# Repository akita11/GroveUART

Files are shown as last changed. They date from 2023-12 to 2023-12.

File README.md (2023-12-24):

# GroveUART

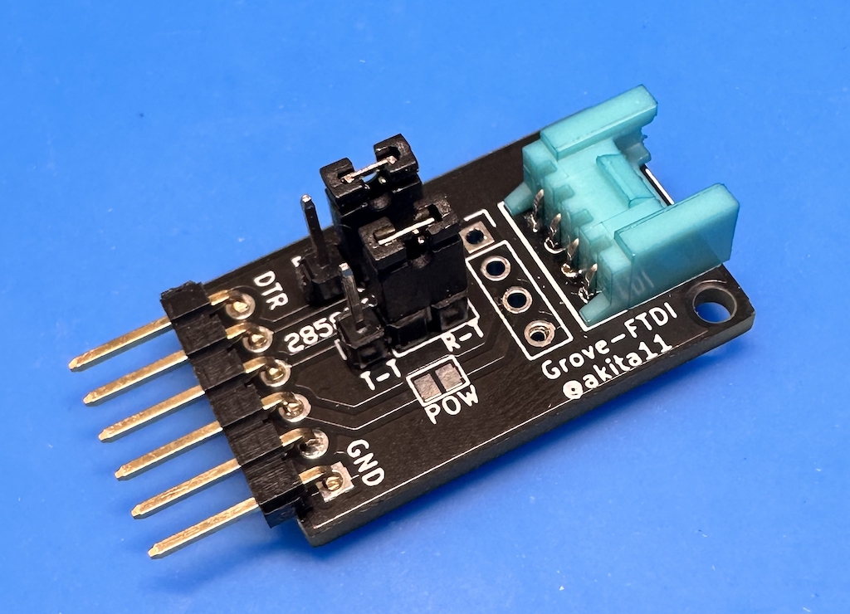
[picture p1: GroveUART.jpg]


GroveケーブルのUART信号を、FTDI-Basic等のUSBシリアル変換器の標準的な6ピンコネクタに接続します。両者の送信(TX)と受信(RX)の接続を切り替えらるので、ストレート結線・リバース結線の両者の使い方ができます。またソルダージャンパをショートすることでFTDI-Basic側の電源をGroveコネクタ側に供給することができます。

## 使い方

M5Stack等からのUART信号の出ているGroveケーブルをGroveコネクタ側に接続し、6ピンコネクタ側には[FTDI-Basic等のUSB-シリアル変換器](https://www.switch-science.com/products/2782)を接続します。Groveケーブル側のUART信号にあわせて、以下のように2箇所のショートピンを設定します。

また裏面のJP1をハンダでショートすることで、FTDI-Basicからの電源をGroveコネクタ側に供給することができます。

### Grove側がUART親機側(M5Stack等)の場合

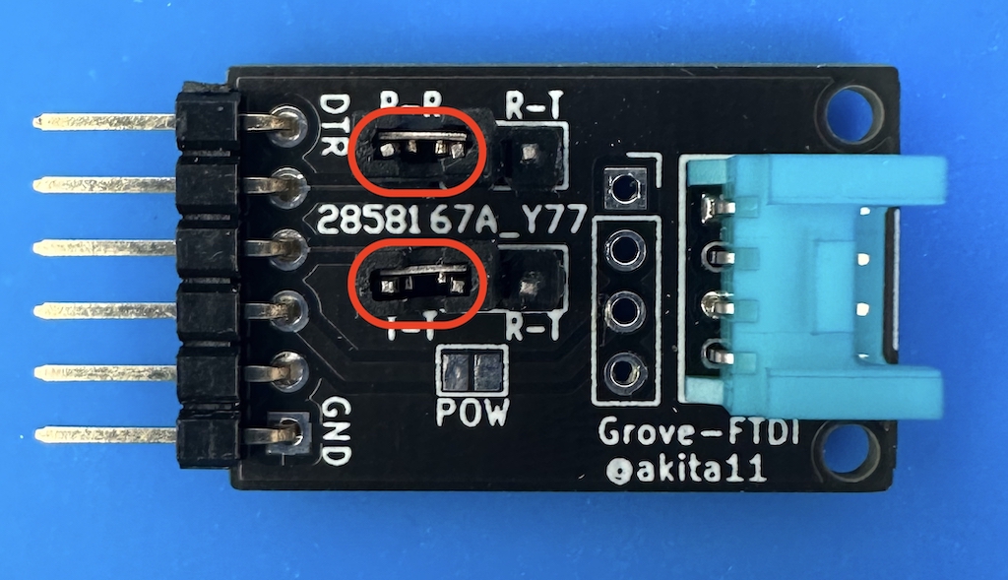
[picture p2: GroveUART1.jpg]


このようにR-R側、T-T側にショートピンを接続します。これにより、以下のように接続されます。

- Groveの1番ピン（端）: FTDI-BasicのTXD(TXo)側
- Groveの2番ピン（その横）: FTDI-basicのRXD(RXi)側

※Groveの1番／2番ピンは、M5StackのPortCのGPIO16(RXD2)/17(TXD2)(Basicの場合)や、GPIO13(RXD2)/14(TXD2)(Core2)です。

### Grove側がUART子機側(Groveセンサ等等)の場合

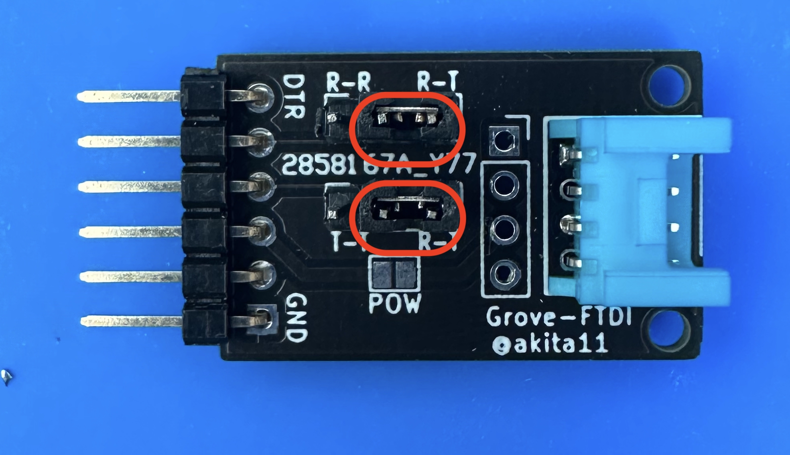
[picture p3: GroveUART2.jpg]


このようにR-T側、R-T側にショートピンを接続します。これにより、以下のように接続されます。

- Groveの1番ピン（端）: FTDI-basicのRXD(RXi)側
- Groveの2番ピン（その横）: FTDI-BasicのTXD(TXo)側

※例えばM5Stack UnitV2では、Groveの1番ピンは"Rx”と表記されていますが、これは「接続先(M5StackBasic等)がRx」という意味ですので、UnitV2にとっては出力(TX)です。

## Author

Junichi Akita (akita@ifdl.jp, @akita11)

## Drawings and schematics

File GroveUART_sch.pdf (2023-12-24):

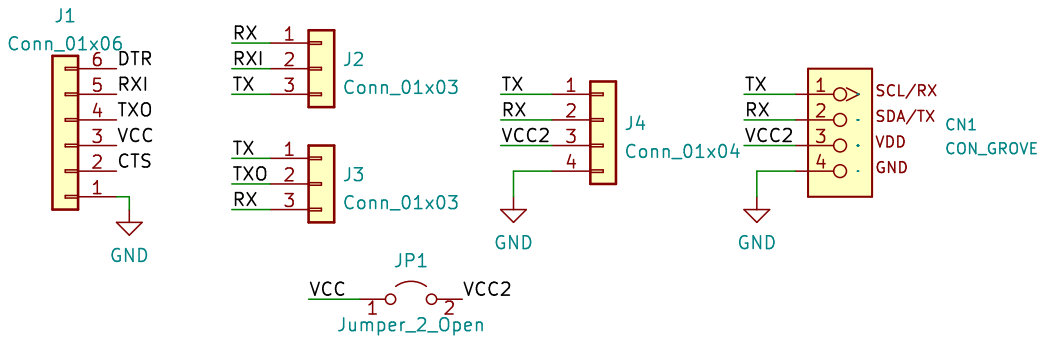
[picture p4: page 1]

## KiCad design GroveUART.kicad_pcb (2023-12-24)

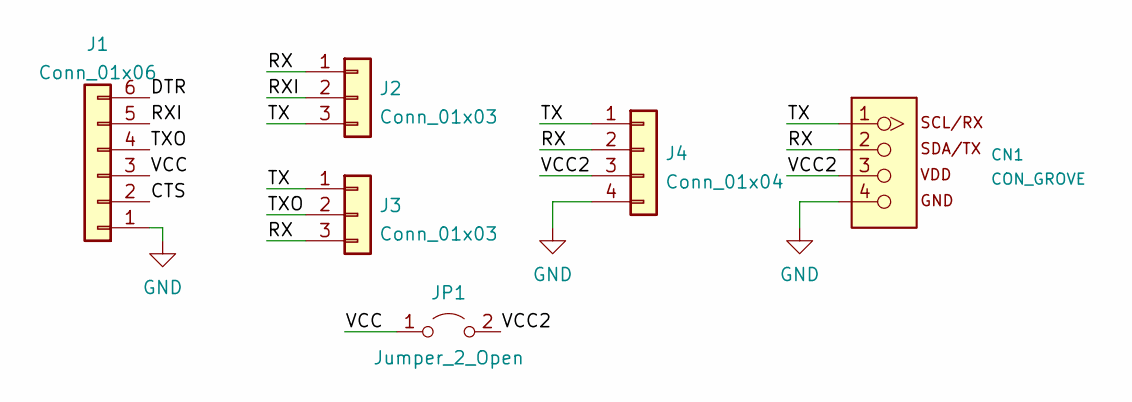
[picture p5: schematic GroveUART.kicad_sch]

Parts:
CN1: CON_GROVE; CON_GROVE_H
J1: Conn_01x06; PinHeader_1x06_P2.54mm_Horizontal
J2, J3: Conn_01x03; PinSocket_1x03_P2.54mm_Vertical
J4: Conn_01x04; PinSocket_1x04_P2.54mm_Vertical
JP1: Jumper_2_Open; SolderJumper-2_P1.3mm_Open_Pad1.0x1.5mm

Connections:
/CTS: J1.2
/DTR: J1.6
/RX: CN1.2, J2.1, J3.3, J4.2
/RXI: J1.5, J2.2
/TX: CN1.1, J2.3, J3.1, J4.1
/TXO: J1.4, J3.2
/VCC: J1.3, JP1.1 (A)
/VCC2: CN1.3, J4.3, JP1.2 (B)
GND: CN1.4, J1.1, J4.4

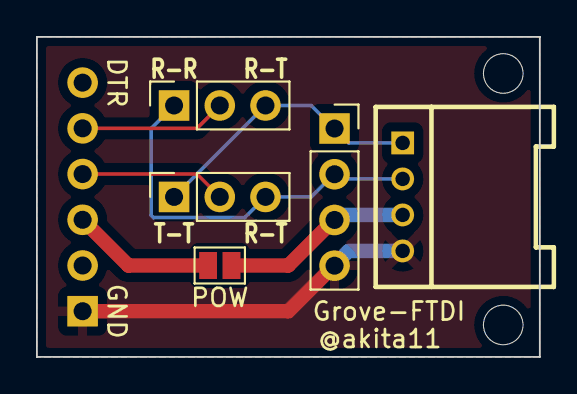
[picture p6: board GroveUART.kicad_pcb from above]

Board: 2 copper layers, 27.9 x 17.8 mm, 6 parts (0 on the bottom side), 7 nets.
